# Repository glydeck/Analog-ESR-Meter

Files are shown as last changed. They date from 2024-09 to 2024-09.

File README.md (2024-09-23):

-----------------------------------------------
# Analog ESR Meter
## Created with KiCAD, OpenSCAD, & Inkscape
#### Posted by glydeck 9/12/2024
-----------------------------------------------

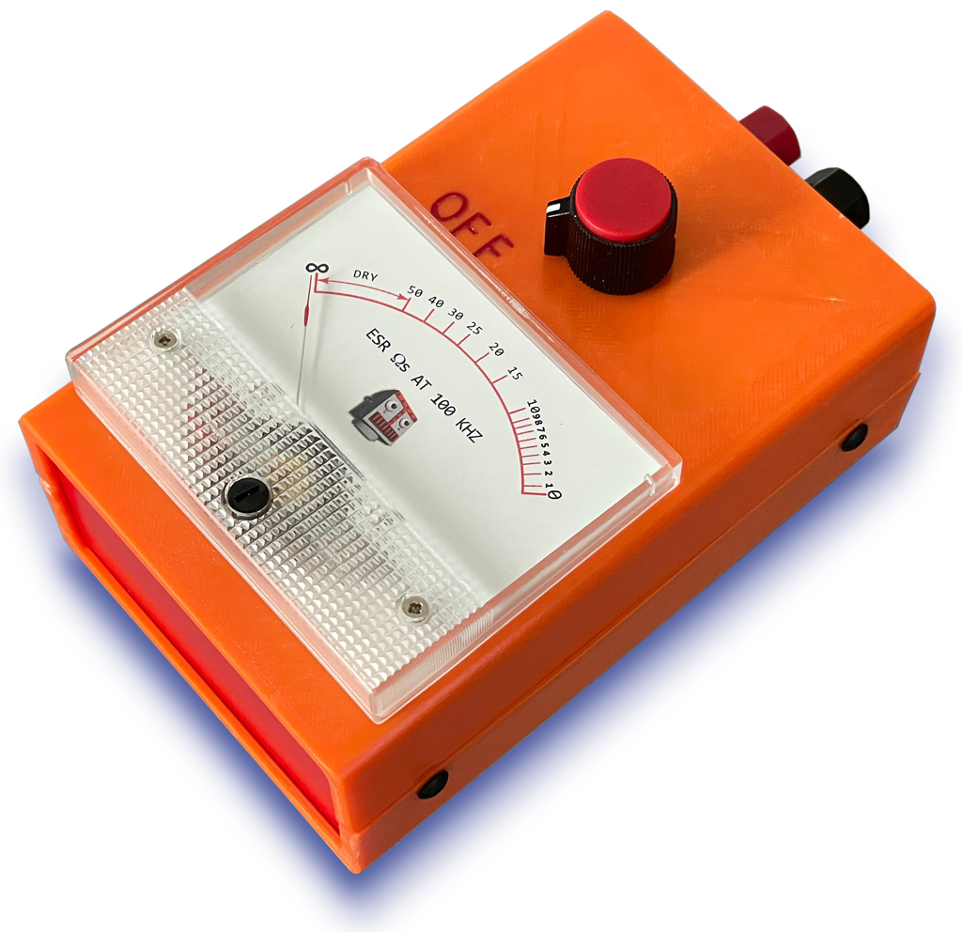
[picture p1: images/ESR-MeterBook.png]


## Introduction
This ESR Meter is an updated version of two articles written by me for Elektor Magazine.

- [**Elektor**](https://www.elektormagazine.com/)
- [**A Simple Analog ESR Meter**](https://www.elektormagazine.com/labs/a-simple-analog-esr-meter)
- [**My First PCB**](https://www.elektormagazine.com/magazine/elektor-261/60678)

The ESR Meter is basically an AC Ohmmeter with special scales and protective circuitry. It provides a continuous reading of series resistance in electrolytic capacitors. It operates at 100 kHz to keep the capacitive reactance factor near zero. The remaining series resistance is due to the electrolyte between the capacitor plates and indicates the state of dryness. Capacitor termination problems also show up plainly due to the continuous ohmic reading.

Additional information including parts list, schematic and circuit description can be found in the file **ESR Meter Manual.pdf** which is included in this repository.

## Requirements to Make your Own ESR Meter
Versions of the following programs:
- [**KiCad EDA**](https://www.kicad.org/)
- [**OpenSCAD**](https://openscad.org/)
- [**Inkscape**](https://github.com/inkscape/inkscape)
- [**The files in this repository**](https://github.com/glydeck/Analog-ESR-Meter)
## Contents

```
    README.md                -This document
    ESR Meter Manual.pdf     -Details for using the meter
    ESR_Box-OpenSCAD         -OpenSCAD code for the meter case
    ESR_Box-STL              -3D printable files for the case
    ESR_Meter_KicadProject   -KiCad project for circuit board
    ESR_MeterScale           -SVG file for the meter scale
    ESR_resources            -Various PDF files
    images                   -Images used throughout the project
```
### KiCad Project

##### 3D KiCad Rendering
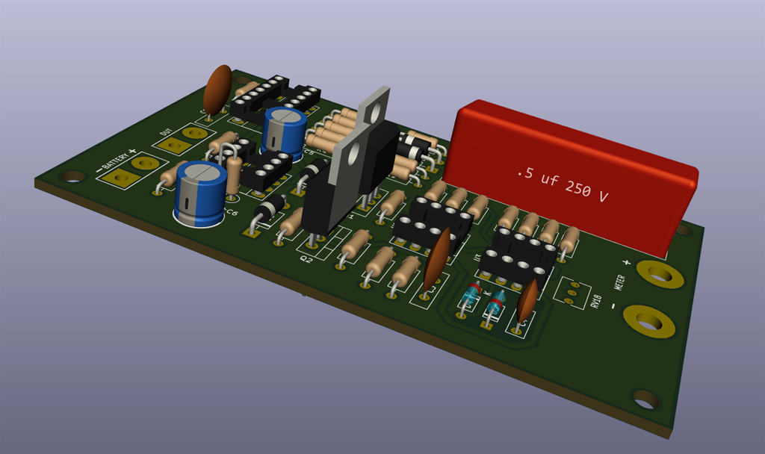
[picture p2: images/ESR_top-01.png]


This project uses a depreciated version of KiCad (Version 5.0.2-5 Mac OSX). At some point in the future I hope to update this to a newer version. For now the files for making the PCB are open source on OSH Park.  Boards can be ordered directly from them as well.
- [**OSH Park ESR Meter Boards**](https://oshpark.com/shared_projects/dSvuQNhP)

##### PCB Top View
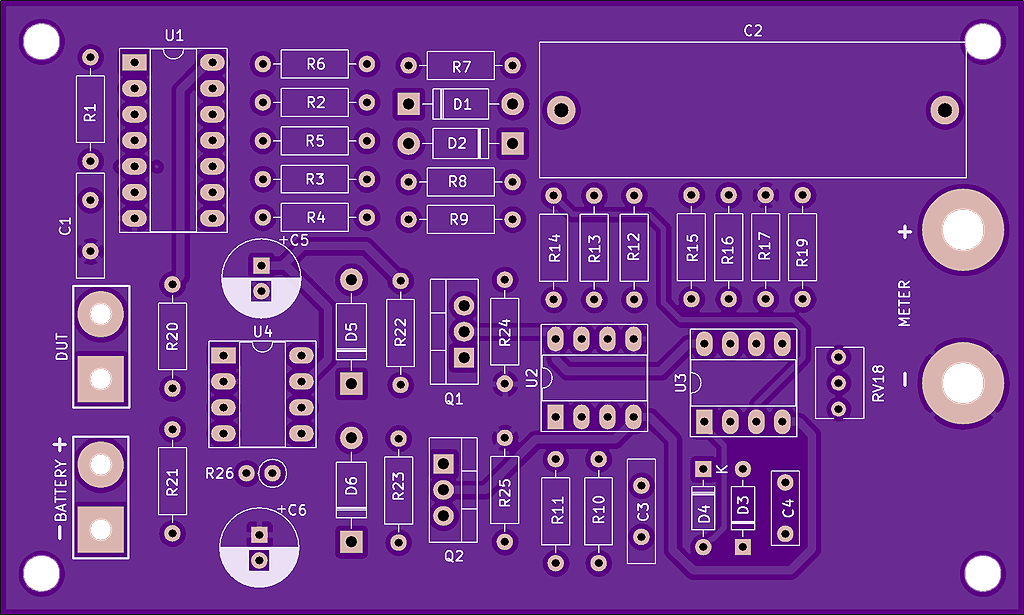
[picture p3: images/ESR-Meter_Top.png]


##### PCB Bottom View
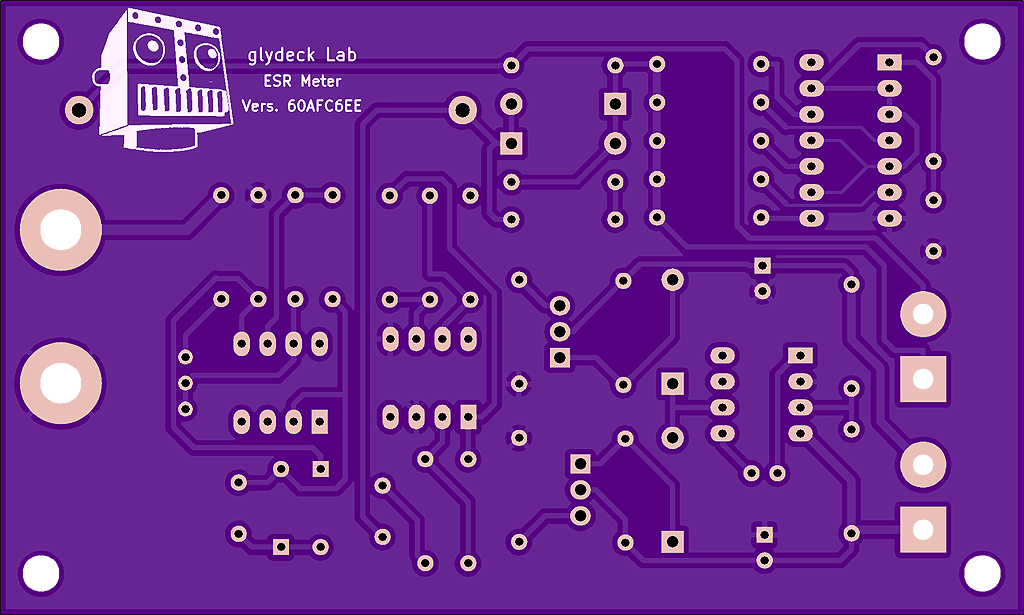
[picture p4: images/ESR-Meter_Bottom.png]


## Meter Case

##### Meter Case Rendered in Blender
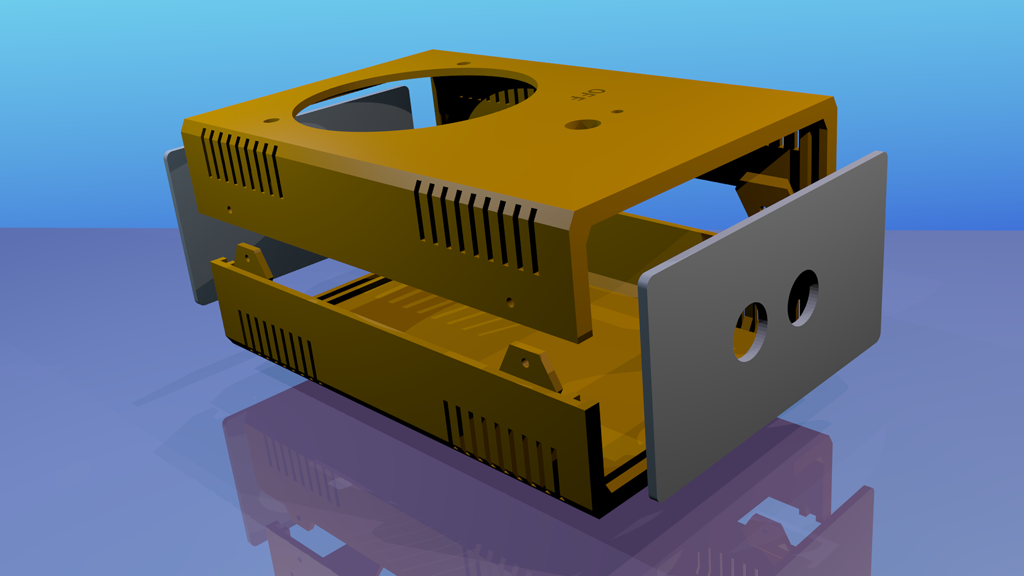
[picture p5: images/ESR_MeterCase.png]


I found the OpenSCAD code for the case on Thingverse:
- [**Thingverse-Ultimate Box Maker**](https://www.thingiverse.com/thing:2938921)

The original code and conncept can be traced back to the French Blog **Hearty GFX**: 
- [**Hearty GFX**](http://heartygfx.blogspot.com/2016/01/the-ultimate-box-maker.html)
 
The code has been maintained and improved on by Joel Ebel on GitHub:
- [**GitHub-Ultimate Box Maker**](https://github.com/jbebel/Ultimate-Box-Maker)

The **Box Maker** code does not accomidate adding holes to the top or bottom of the case.  It also does not accomidate custom geometries, such as the battery holder, being added to the inside of the box.

In the OpenScad file **ESR_Box_all.scad** the extra holes in the top of the case and battery holder are included at the end of the file. These added geometries including holes for the meter, potentiometer, added battery cage are included starting on line 419.  The Battery holder runs from line 432 to line 487. The holes for the meter, switch and text are difference geometries subtracted from the case. This code runs from line 496 thru line 569.

##### Meter Case Rendered in OpenSCAD
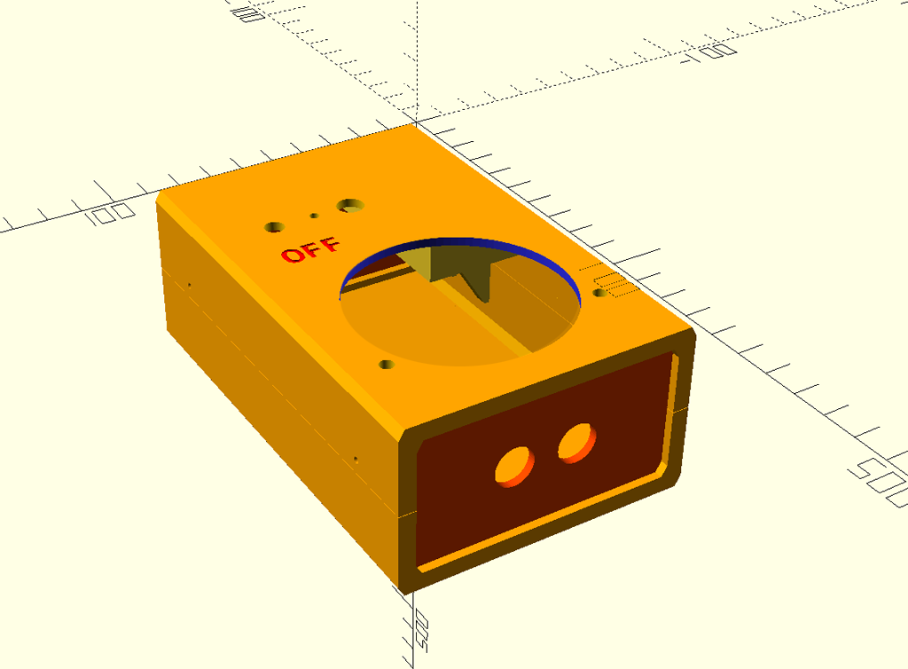
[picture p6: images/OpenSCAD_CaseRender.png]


### STL Files

There are two sets of STL files that are 3D printer ready.  I used Cura to generate the the G-Code for my printer and printed the case with a Creality Ender Model 3 printer.

The version one folder has a seperate bracket to help hold the 9 volt battery in place.  This piece would need to be glued in place on the bottom shell wall.

The version two folder this bracket is integral to the print of the bottom shell of the case.

## Meter Scale
The Meter scale graphic was created using **Inkscape**.  
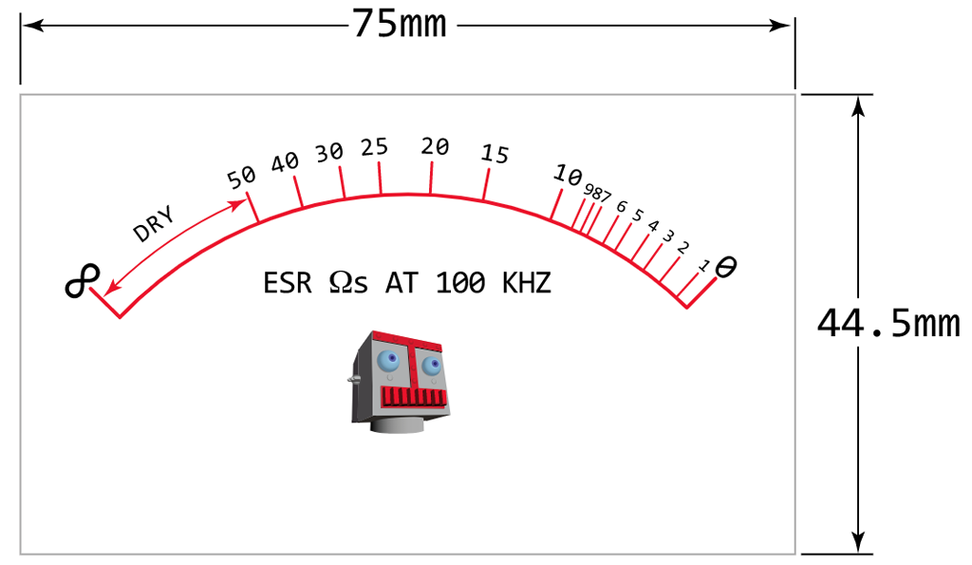
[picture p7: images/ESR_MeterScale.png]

## Assembly of ESR Meter
The meter is very easy to assemble.  After stuffing the Printed Circuit Board with components wires can be attached to to the PCB.  These wires can then be attached to the components in the case.  That includes potentiometer with integrated on/off switch, the binding posts and the 9V battery clip.  Two images are provided to show those connections.  When completed the PCB can be turned over and bolted to the back of the meter.  The meter acts as a holding device for the circuit board.

#### Stuffed Board
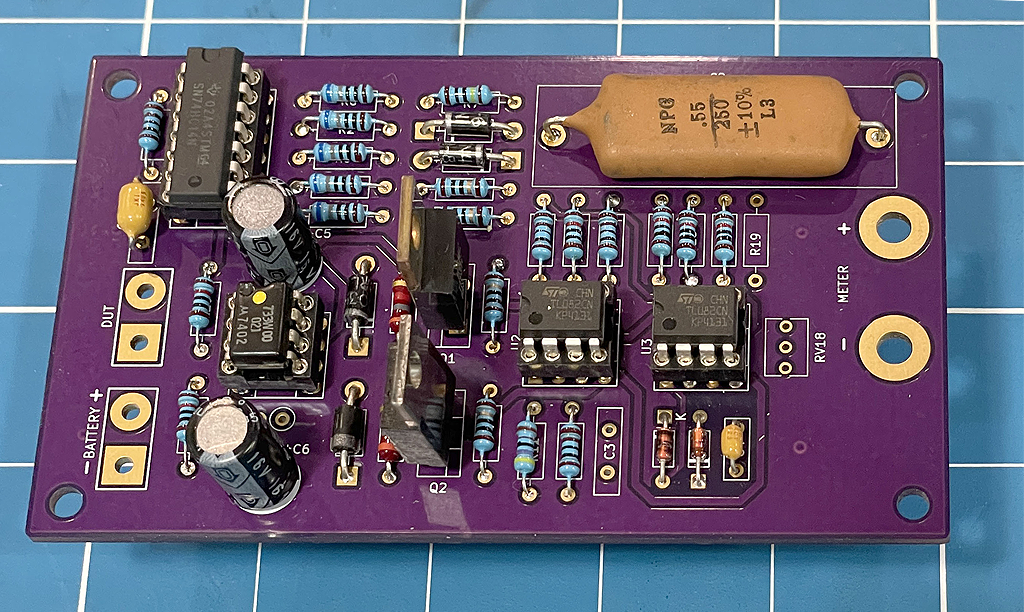
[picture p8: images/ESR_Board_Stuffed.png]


#### Wiring to Potentiometer, Binding Posts, & Battery Clip
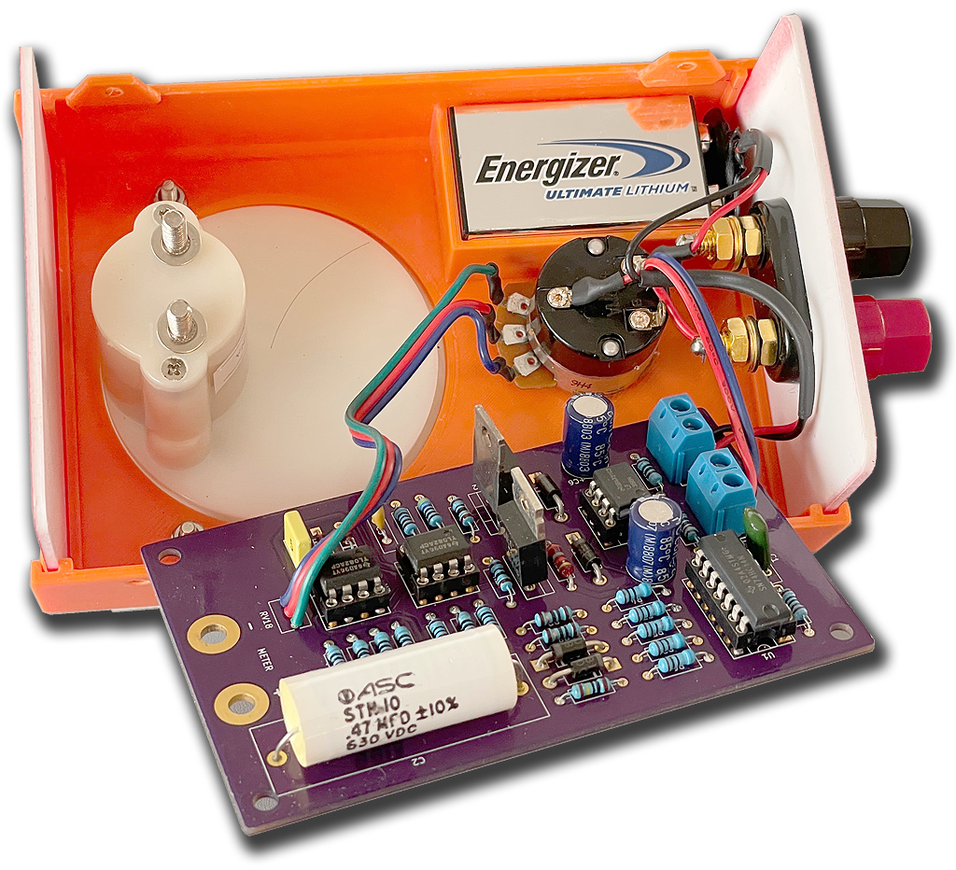
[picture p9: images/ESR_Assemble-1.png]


#### Closer View of Internal Wiring
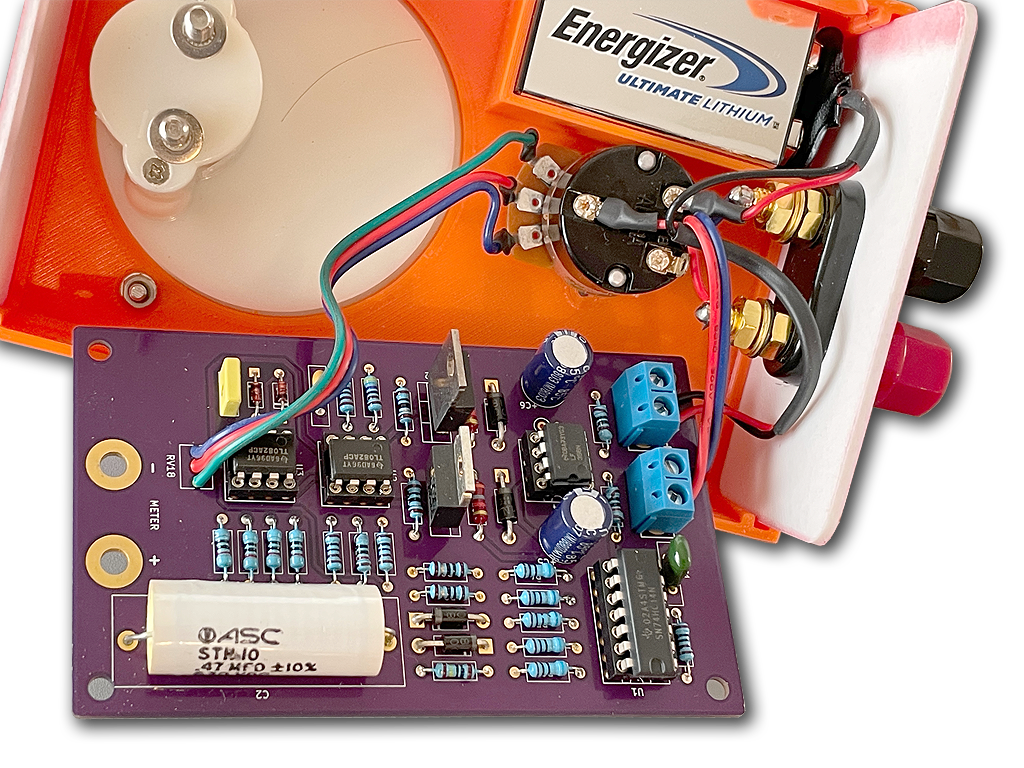
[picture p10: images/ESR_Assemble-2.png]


#### Board Attached to the Meter
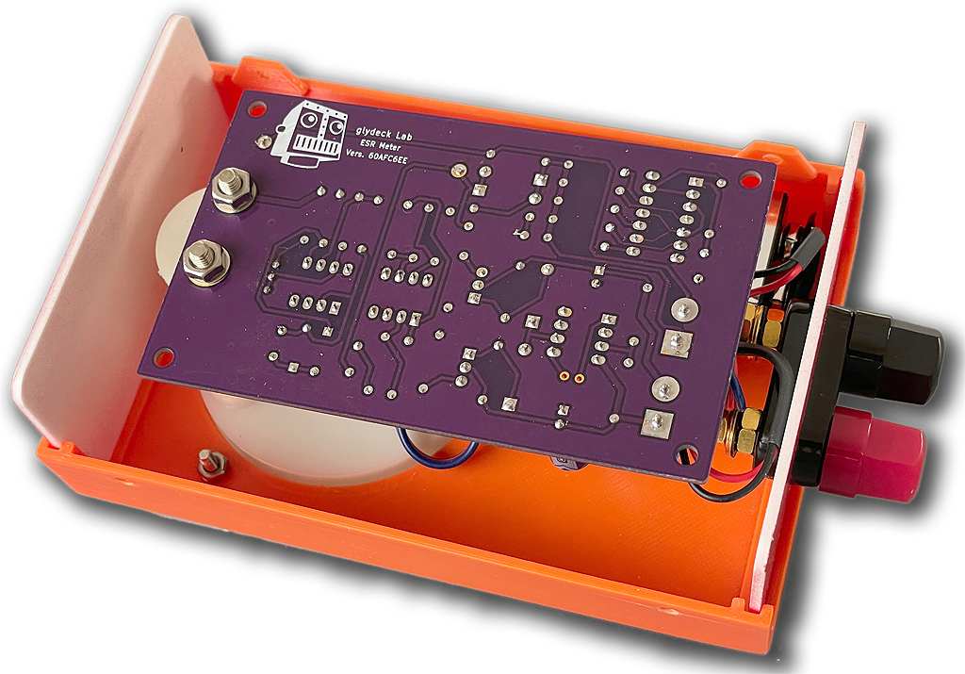
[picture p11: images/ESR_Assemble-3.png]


### ESR Resources
Description of included PDF files relevant to this project:

- Insert Analog_Panel_Meter.pdf - **Meter Cutout**
- sboa068.pdf - **Burr Brown App Note Absolute Value Circuits**
- Schmitt_Trigger_Oscillators.pdf - **Schmitt Trigger Oscillators**
- snoa998.pdf - **Texas Instruments App Note Relaxation oscillator circuit**
- US4216424.pdf - **Untited States Patent for an ESR Meter**
- US6677764.pdf - **United States Patent for Protecting Test Equipment**

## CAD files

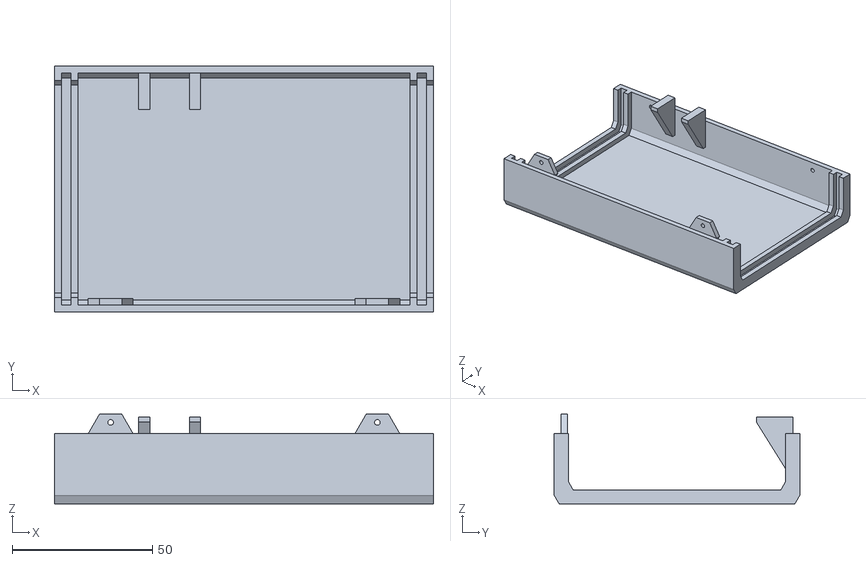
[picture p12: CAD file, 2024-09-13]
ESR_Box-STL/Version_02/ESR_Box_bottom_w-rotate.stl
135.0 x 87.5 x 31.9

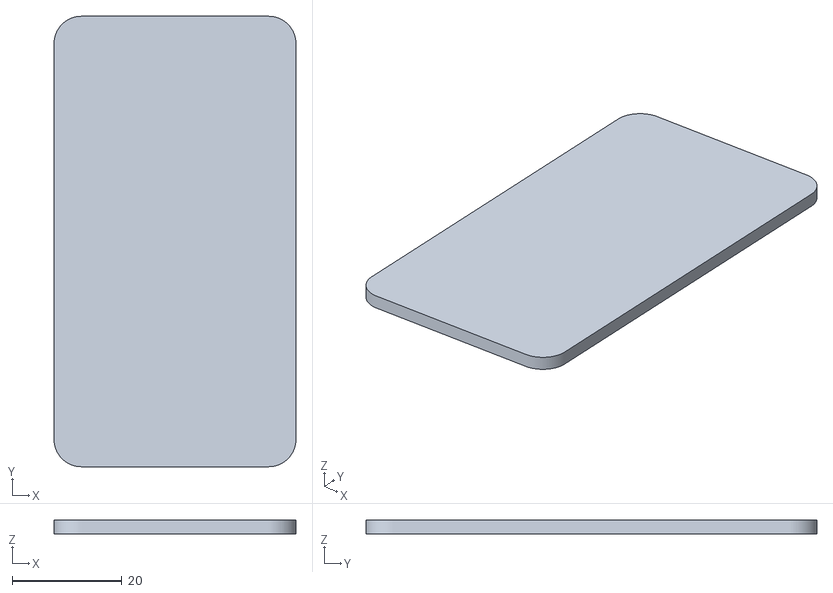
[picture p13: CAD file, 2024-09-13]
ESR_Box-STL/Version_02/ESR_Box_back.stl
44.1 x 82.1 x 2.50

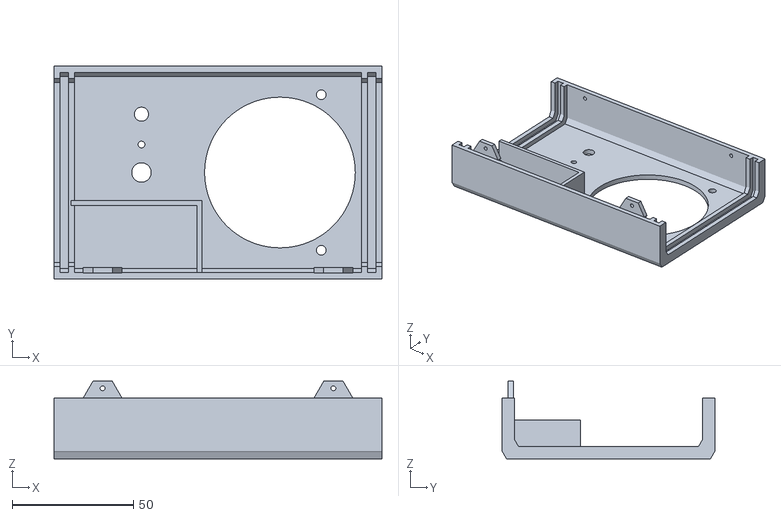
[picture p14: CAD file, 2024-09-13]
ESR_Box-STL/Version_02/ESR_Box_top_w-rotate.stl
135.0 x 87.5 x 31.9

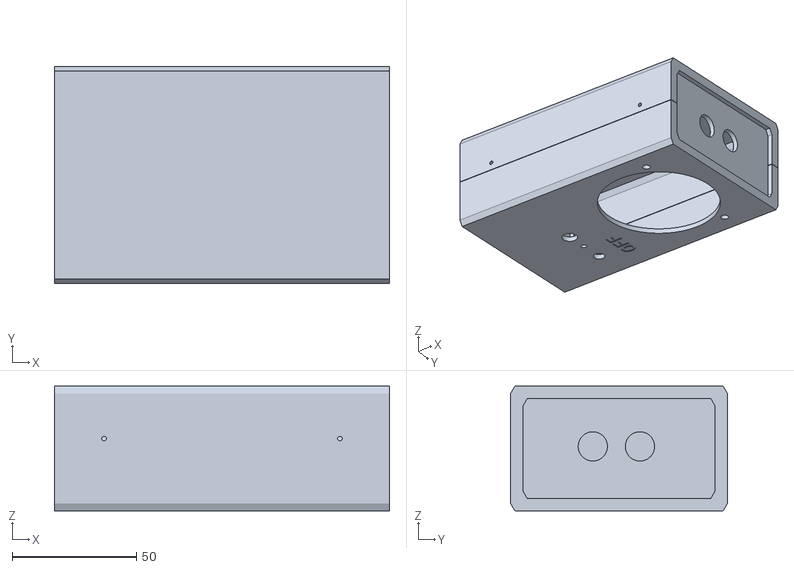
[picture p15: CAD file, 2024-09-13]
ESR_Box-STL/Version_02/ESR_Box_all.stl
135.0 x 87.5 x 50.2

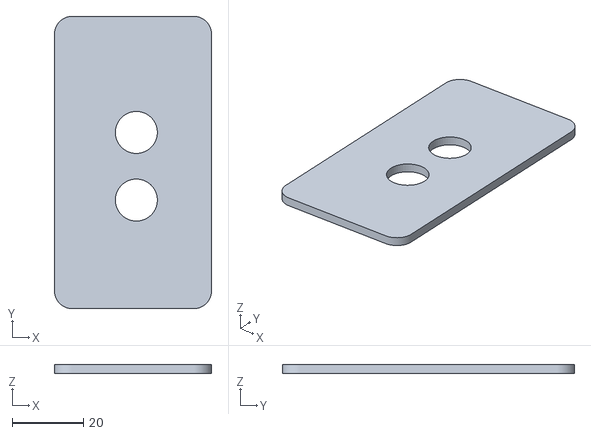
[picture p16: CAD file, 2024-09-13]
ESR_Box-STL/Version_02/ESR_Box_front.stl
44.1 x 82.1 x 2.50

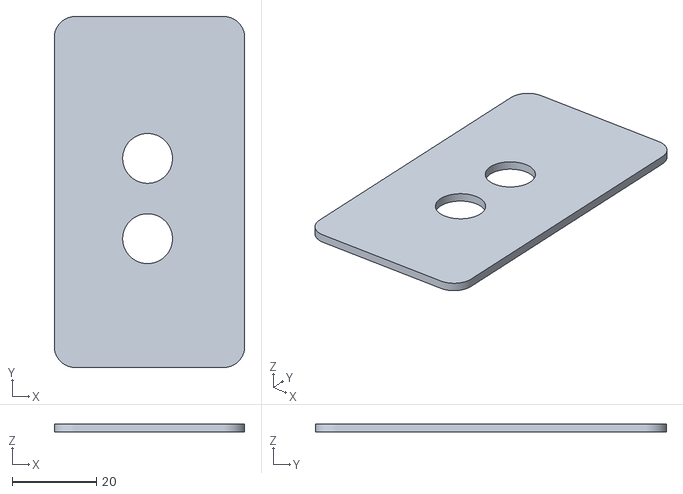
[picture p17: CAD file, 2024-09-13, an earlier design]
ESR_Box-STL/Version_01/ESR_Box_front_f5.stl
45.1 x 83.1 x 2.00

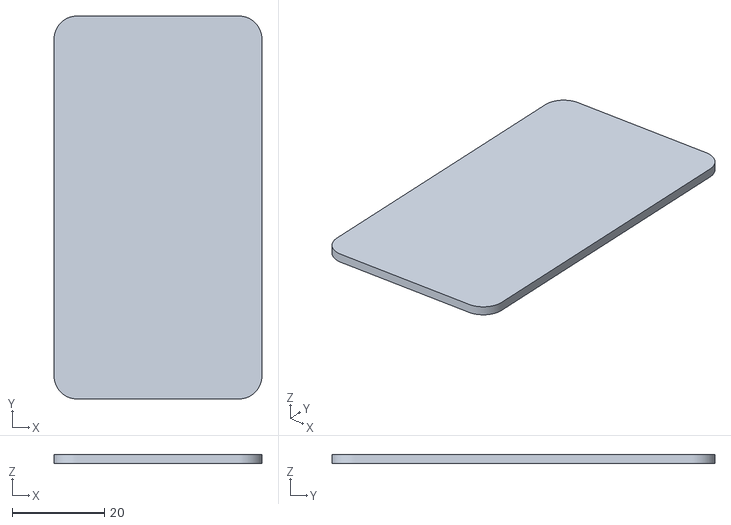
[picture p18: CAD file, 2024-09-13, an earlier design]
ESR_Box-STL/Version_01/ESR_Box_back_f5.stl
45.1 x 83.1 x 2.00

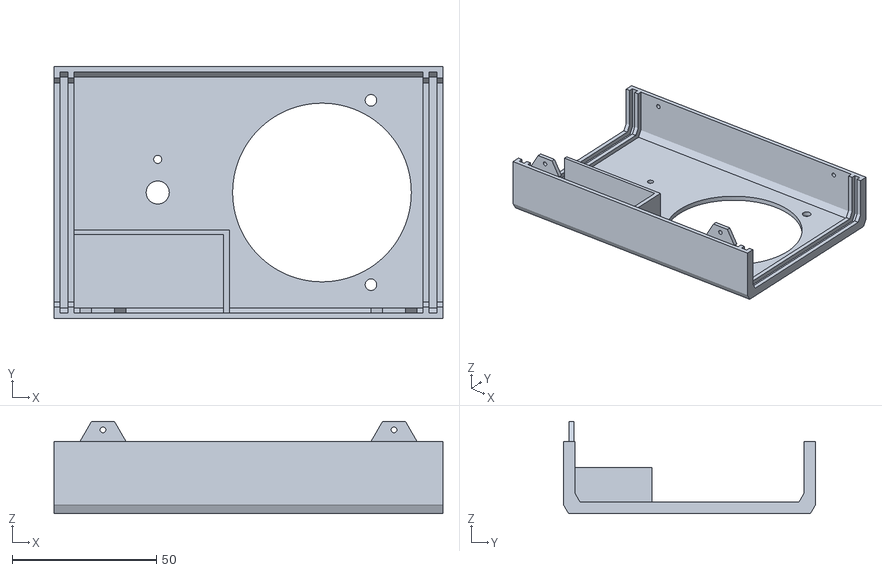
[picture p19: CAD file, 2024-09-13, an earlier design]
ESR_Box-STL/Version_01/ESR_Box_top.stl
135.0 x 87.5 x 31.9

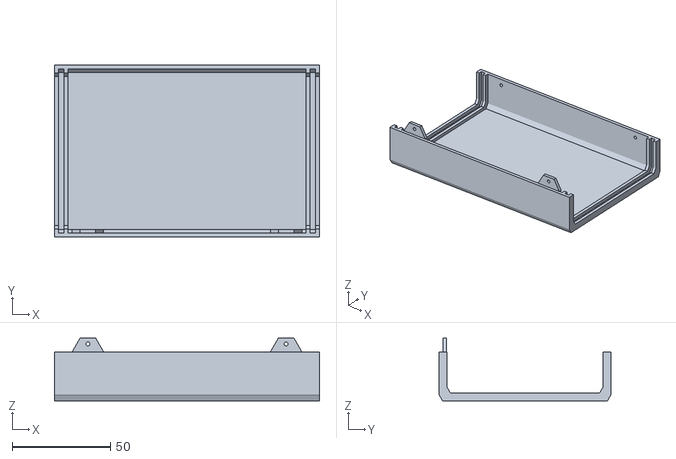
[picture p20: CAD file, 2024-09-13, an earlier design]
ESR_Box-STL/Version_01/ESR_Box_bottom.stl
135.0 x 87.5 x 31.9

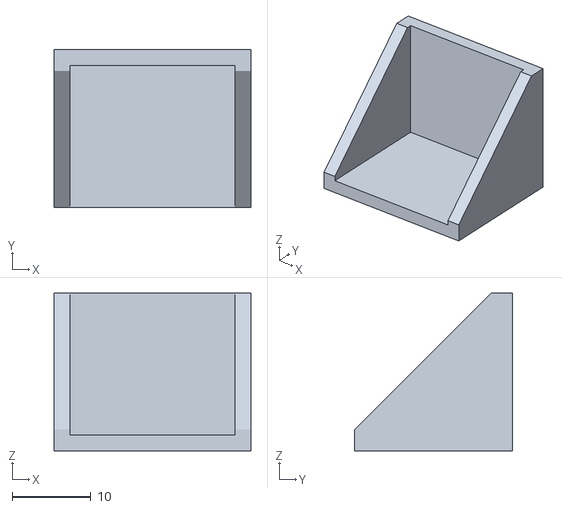
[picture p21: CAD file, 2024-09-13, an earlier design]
ESR_Box-STL/Version_01/battery_Bracket.stl
25.0 x 20.0 x 20.0

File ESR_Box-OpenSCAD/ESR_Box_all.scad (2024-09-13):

$vpr = [237, 0, 301];
$vpt = [62, 44, 29];
$vpd = 471;


/*//////////////////////////////////////////////////////////////////
              -   FB Aka Heartman/Hearty 2016
              -   OpenScad Parametric Box
              -   http://heartygfx.blogspot.com
              -   https://www.thingiverse.com/thing:2938921
              -   https://github.com/jbebel/Ultimate-Box-Maker             
              -   CC BY-NC 3.0 License 
////////////////////////////////////////////////////////////////////

12/02/2016 - Fixed minor bug 
28/02/2016 - Added holes ventilation option                    
09/03/2016 - Added PCB feet support, fixed the shell artefact on export mode. 

*/ ////////////////////////// - Info - //////////////////////////////

// All coordinates are starting as integrated circuit pins.
// From the top view :

//   CoordD           <---       CoordC
//                                 ^
//                                 ^
//                                 ^
//   CoordA           --->       CoordB

////////////////////////////////////////////////////////////////////

/////////////////////////// - Box parameters - //////////////////////

/* [Box dimensions] */
// - Longueur - Length  
Length = 135;
// - Largeur - Width
Width = 88;
// - Hauteur - Height  
Height = 50;
// - Epaisseur - Wall thickness  
Thick = 2.5; //[2:5]  

/* [Box options] */
// - DiamÃ¨tre Coin arrondi - Filet diameter  
Filet = 2; //[0.1:12] 
// - lissage de l'arrondi - Filet smoothness  
Resolution = 1; //[1:100] 
// - TolÃ©rance - Tolerance (Panel/rails gap)
m = 0.9;
// Pieds PCB - PCB feet (x4) 
PCBFeet = 0; // [0:No, 1:Yes]
// - Decorations to ventilation holes
Vent = 0; // [0:No, 1:Yes]
// - Decoration-Holes width (in mm)
Vent_width = 0;

/////////////////////////// - PCB parameters - //////////////////////

/* [PCB_Feet] */
//All dimensions are from the center foot axis

// - Coin bas gauche - Low left corner X position
PCBPosX = 0;
// - Coin bas gauche - Low left corner Y position
PCBPosY = 0;
// - Longueur PCB - PCB Length
PCBLength = 0;
// - Largeur PCB - PCB Width
PCBWidth = 0;
// - Heuteur pied - Feet height
FootHeight = 0;
// - DiamÃ¨tre pied - Foot diameter
FootDia = 0;
// - DiamÃ¨tre trou - Hole diameter
FootHole = 0;

////////////////////////////////////////////////////////////////////////
//////////////////////// <- Render Manager -> //////////////////////////
////////////////////////////////////////////////////////////////////////

/* [STL element to export] */
//Coque haut - Top shell
TShell = 1; // [0:No, 1:Yes]
//Coque bas- Bottom shell
BShell = 1; // [0:No, 1:Yes]
//Panneau avant - Front panel
FPanL = 1; // [0:No, 1:Yes]
//Panneau arriÃ¨re - Back panel  
BPanL = 1; // [0:No, 1:Yes]

/* [Hidden] */
// - Couleur coque - Shell color  
Couleur1 = "Orange";
// - Couleur panneaux - Panels color    
Couleur2 = "OrangeRed";
// Thick X 2 - making decorations thicker if it is a vent to make sure they go through shell
Dec_Thick = Vent ? Thick * 2 : Thick;
// - Depth decoration
Dec_size = Vent ? Thick * 2 : 0.8;

////////////////// - Generic rounded box - ///////////////

module RoundBox($a = Length, $b = Width, $c = Height) { // Cube bords arrondis
  $fn = Resolution;
  translate([0, Filet, Filet]) {
    minkowski() {
      cube([$a - (Length / 2), $b - (2 * Filet), $c - (2 * Filet)], center = false);
      rotate([0, 90, 0]) {
        cylinder(r = Filet, h = Length / 2, center = false);
      }
    }
  }
} // End of RoundBox Module

////////////////////////////////// - Module Coque/Shell - //////////////////////////////////         

module Coque() { //Coque - Shell  
  Thick = Thick * 2;
  difference() {
    difference() { //sides decoration
      union() {
        difference() { //soustraction de la forme centrale - Substraction Fileted box

          difference() { //soustraction cube median - Median cube slicer
            union() { //union               
              difference() { //Coque    
                RoundBox();
                translate([Thick / 2, Thick / 2, Thick / 2]) {
                  RoundBox($a = Length - Thick, $b = Width - Thick, $c = Height - Thick);
                }
              } //Fin diff Coque                            
              difference() { //largeur Rails        
                translate([Thick + m, Thick / 2, Thick / 2]) { // Rails
                  RoundBox($a = Length - ((2 * Thick) + (2 * m)), $b = Width - Thick, $c = Height - (Thick * 2));
                } //fin Rails
                translate([((Thick + m / 2) * 1.55), Thick / 2, Thick / 2 + 0.1]) { // +0.1 added to avoid the artefact
                  RoundBox($a = Length - ((Thick * 3) + 2 * m), $b = Width - Thick, $c = Height - Thick);
                }
              } //Fin largeur Rails
            } //Fin union                                   
            translate([-Thick, -Thick, Height / 2]) { // Cube Ã  soustraire
              cube([Length + 100, Width + 100, Height], center = false);
            }
          } //fin soustraction cube median - End Median cube slicer
          translate([-Thick / 2, Thick, Thick]) { // Forme de soustraction centrale 
            RoundBox($a = Length + Thick, $b = Width - Thick * 2, $c = Height - Thick);
          }
        }

        difference() { // wall fixation box legs
          union() {
            translate([3 * Thick + 5, Thick, Height / 2]) {
              rotate([90, 0, 0]) {
                $fn = 6;
                cylinder(d = 16, Thick / 2);
              }
            }

            translate([Length - ((3 * Thick) + 5), Thick, Height / 2]) {
              rotate([90, 0, 0]) {
                $fn = 6;
                cylinder(d = 16, Thick / 2);
              }
            }

          }
          translate([4, Thick + Filet, Height / 2 - 57]) {
            rotate([45, 0, 0]) {
              cube([Length, 40, 40]);
            }
          }
          translate([0, -(Thick * 1.46), Height / 2]) {
            cube([Length, Thick * 2, 10]);
          }
        } //Fin fixation box legs
      }

      union() { // outbox sides decorations

        for (i = [0: Thick: Length / 4]) {

          // Ventilation holes part code submitted by Ettie - Thanks ;) 
          translate([10 + i, -Dec_Thick + Dec_size, 1]) {
            cube([Vent_width, Dec_Thick, Height / 4]);
          }
          translate([(Length - 10) - i, -Dec_Thick + Dec_size, 1]) {
            cube([Vent_width, Dec_Thick, Height / 4]);
          }
          translate([(Length - 10) - i, Width - Dec_size, 1]) {
            cube([Vent_width, Dec_Thick, Height / 4]);
          }
          translate([10 + i, Width - Dec_size, 1]) {
            cube([Vent_width, Dec_Thick, Height / 4]);
          }

        } // fin de for
        // }
      } //fin union decoration
    } //fin difference decoration

    union() { //sides holes
      $fn = 50;
      translate([3 * Thick + 5, 20, Height / 2 + 4]) {
        rotate([90, 0, 0]) {
          cylinder(d = 2, 20);
        }
      }
      translate([Length - ((3 * Thick) + 5), 20, Height / 2 + 4]) {
        rotate([90, 0, 0]) {
          cylinder(d = 2, 20);
        }
      }
      translate([3 * Thick + 5, Width + 5, Height / 2 - 4]) {
        rotate([90, 0, 0]) {
          cylinder(d = 2, 20);
        }
      }
      translate([Length - ((3 * Thick) + 5), Width + 5, Height / 2 - 4]) {
        rotate([90, 0, 0]) {
          cylinder(d = 2, 20);
        }
      }
    } //fin de sides holes

  } //fin de difference holes
} // fin coque 

////////////////////////////// - Experiment - ///////////////////////////////////////////

/////////////////////// - Foot with base filet - /////////////////////////////
module foot(FootDia, FootHole, FootHeight) {
  Filet = 2;
  color(Couleur1)
  translate([0, 0, Filet - 1.5])
  difference() {

    difference() {
      //translate ([0,0,-Thick]){
      cylinder(d = FootDia + Filet, FootHeight - Thick, $fn = 100);
      //}
      rotate_extrude($fn = 100) {
        translate([(FootDia + Filet * 2) / 2, Filet, 0]) {
          minkowski() {
            square(10);
            circle(Filet, $fn = 100);
          }
        }
      }
    }
    cylinder(d = FootHole, FootHeight + 1, $fn = 100);
  }
} // Fin module foot

module Feet() {
  //////////////////// - PCB only visible in the preview mode - /////////////////////    
  translate([3 * Thick + 2, Thick + 5, FootHeight + (Thick / 2) - 0.5]) {

    %
    square([PCBLength + 10, PCBWidth + 10]);
    translate([PCBLength / 2, PCBWidth / 2, 0.5]) {
      color("Olive") %
        text("PCB", halign = "center", valign = "center", font = "Arial black");
    }
  } // Fin PCB
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

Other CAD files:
ESR_Box-OpenSCAD/ESR_Box_back.scad
ESR_Box-OpenSCAD/ESR_Box_bottom.scad
ESR_Box-OpenSCAD/ESR_Box_bottom_w-rotate.scad
ESR_Box-OpenSCAD/ESR_Box_front.scad
ESR_Box-OpenSCAD/ESR_Box_top.scad
ESR_Box-OpenSCAD/ESR_Box_top_w-rotate.scad

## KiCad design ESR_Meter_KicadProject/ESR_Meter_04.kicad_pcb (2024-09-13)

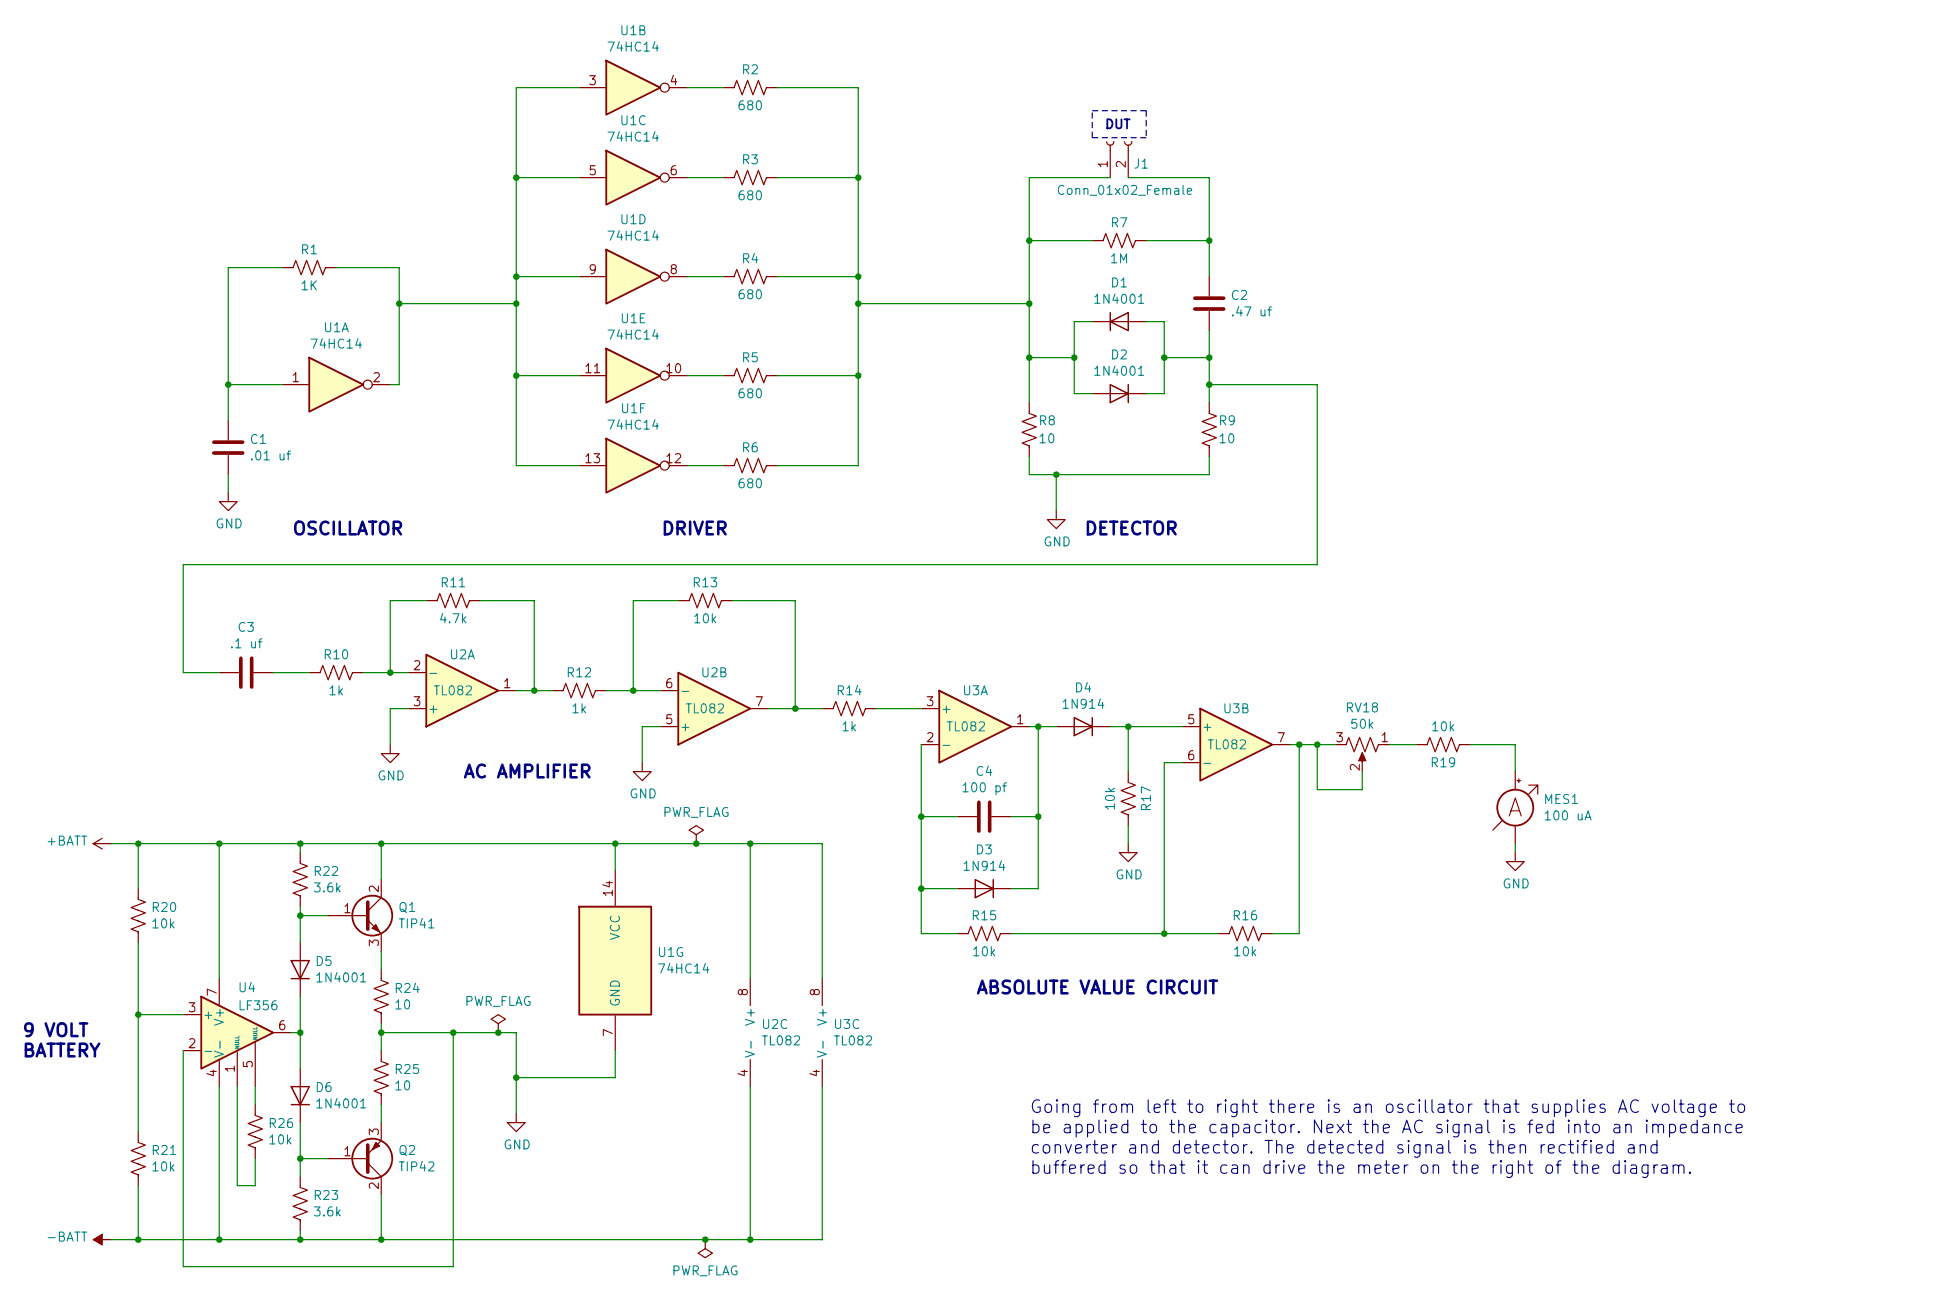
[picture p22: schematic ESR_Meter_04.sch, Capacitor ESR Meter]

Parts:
C1: .01 uf; C_Disc_D10.0mm_W2.5mm_P5.00mm
C2: .47 uf; C_Rect_L41.5mm_W13.0mm_P37.50mm_MKS4
C3: .1 uf; C_Disc_D10.0mm_W2.5mm_P5.00mm
C4: 100 pf; C_Disc_D7.0mm_W2.5mm_P5.00mm
D1, D2, D5, D6: 1N4001; D_DO-41_SOD81_P10.16mm_Horizontal
D3, D4: 1N914; D_DO-35_SOD27_P7.62mm_Horizontal
J1: Conn_01x02_Female; SolderWirePad_1x02_P7.62mm_Drill2mm
MES1: 100 uA; Analog Meter
Q1: TIP41; TO-220-3_Vertical
Q2: TIP42; TO-220-3_Vertical
R1: 1K; R_Axial_DIN0207_L6.3mm_D2.5mm_P10.16mm_Horizontal
R2, R3, R4, R5, R6: 680; R_Axial_DIN0207_L6.3mm_D2.5mm_P10.16mm_Horizontal
R7: 1M; R_Axial_DIN0207_L6.3mm_D2.5mm_P10.16mm_Horizontal
R8, R9, R24, R25: 10; R_Axial_DIN0207_L6.3mm_D2.5mm_P10.16mm_Horizontal
R10, R12, R14: 1k; R_Axial_DIN0207_L6.3mm_D2.5mm_P10.16mm_Horizontal
R11: 4.7k; R_Axial_DIN0207_L6.3mm_D2.5mm_P10.16mm_Horizontal
R13, R15, R16, R17, R19, R20, R21: 10k; R_Axial_DIN0207_L6.3mm_D2.5mm_P10.16mm_Horizontal
R22, R23: 3.6k; R_Axial_DIN0207_L6.3mm_D2.5mm_P10.16mm_Horizontal
R26: 10k; R_Axial_DIN0207_L6.3mm_D2.5mm_P2.54mm_Vertical
RV18: 50k; Potentiometer_Bourns_3266Y_Vertical
U1: 74HC14; DIP-14_W7.62mm_Socket_LongPads
U2, U3: TL082; DIP-8_W7.62mm_Socket_LongPads
U4: LF356; DIP-8_W7.62mm_Socket_LongPads

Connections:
+BATT: Q1.2 (C), R20.1, R22.1, U1.14 (VCC), U2.8 (V+), U3.8 (V+), U4.7 (V+); also elsewhere on the board
-BATT: Q2.2 (C), R21.2, R23.2, U2.4 (V-), U3.4 (V-), U4.4 (V-); also elsewhere on the board
GND: C1.1, MES1.1 (-), R8.1, R9.1, R17.1, R24.2, R25.1, U1.7 (GND), U2.3 (+), U2.5 (+), U4.2 (-); also elsewhere on the board
unnamed: C1.2, R1.2, U1.1
unnamed: C2.1, C3.2, D1.2 (A), D2.1 (K), R9.2
unnamed 5: C2.2, J1.2, R7.1; also elsewhere on the board
unnamed: C3.1, R10.2
unnamed: C4.1, D3.1 (K), D4.2 (A), U3.1
unnamed: C4.2, D3.2 (A), R15.2, U3.2 (-)
unnamed 9: D1.1 (K), D2.2 (A), J1.1, R2.1, R3.1, R4.1, R5.1, R6.1, R7.2, R8.2; also elsewhere on the board
unnamed: D4.1 (K), R17.2, U3.5 (+)
unnamed: D5.1 (K), D6.2 (A), U4.6
unnamed: D5.2 (A), Q1.1 (B), R22.2
unnamed: D6.1 (K), Q2.1 (B), R23.1
unnamed 14: MES1.2 (+), R19.2; also elsewhere on the board
unnamed: Q1.3 (E), R24.1
unnamed: Q2.3 (E), R25.2
unnamed: R1.1, U1.2, U1.3, U1.5, U1.9, U1.11, U1.13
unnamed: R2.2, U1.4
unnamed: R3.2, U1.6
unnamed: R4.2, U1.8
unnamed: R5.2, U1.10
unnamed: R6.2, U1.12
unnamed: R10.1, R11.2, U2.2 (-)
unnamed: R11.1, R12.2, U2.1
unnamed: R12.1, R13.2, U2.6 (-)
unnamed: R13.1, R14.2, U2.7
unnamed: R14.1, U3.3 (+)
unnamed: R15.1, R16.2, U3.6 (-)
unnamed: R16.1, RV18.2, RV18.3, U3.7
unnamed: R19.1, RV18.1
unnamed: R20.2, R21.1, U4.3 (+)
unnamed: R26.1, U4.5 (NULL)
unnamed: R26.2, U4.1 (NULL)

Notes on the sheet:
DUT
OSCILLATOR
DRIVER
DETECTOR
AC AMPLIFIER
ABSOLUTE VALUE CIRCUIT
Going from left to right there is an oscillator that supplies AC voltage to be applied to the capacitor. Next the AC signal is fed into an impedance converter and detector. The detected signal is then rectified and buffered so that it can drive the meter on the right of the diagram.
9 VOLT BATTERY

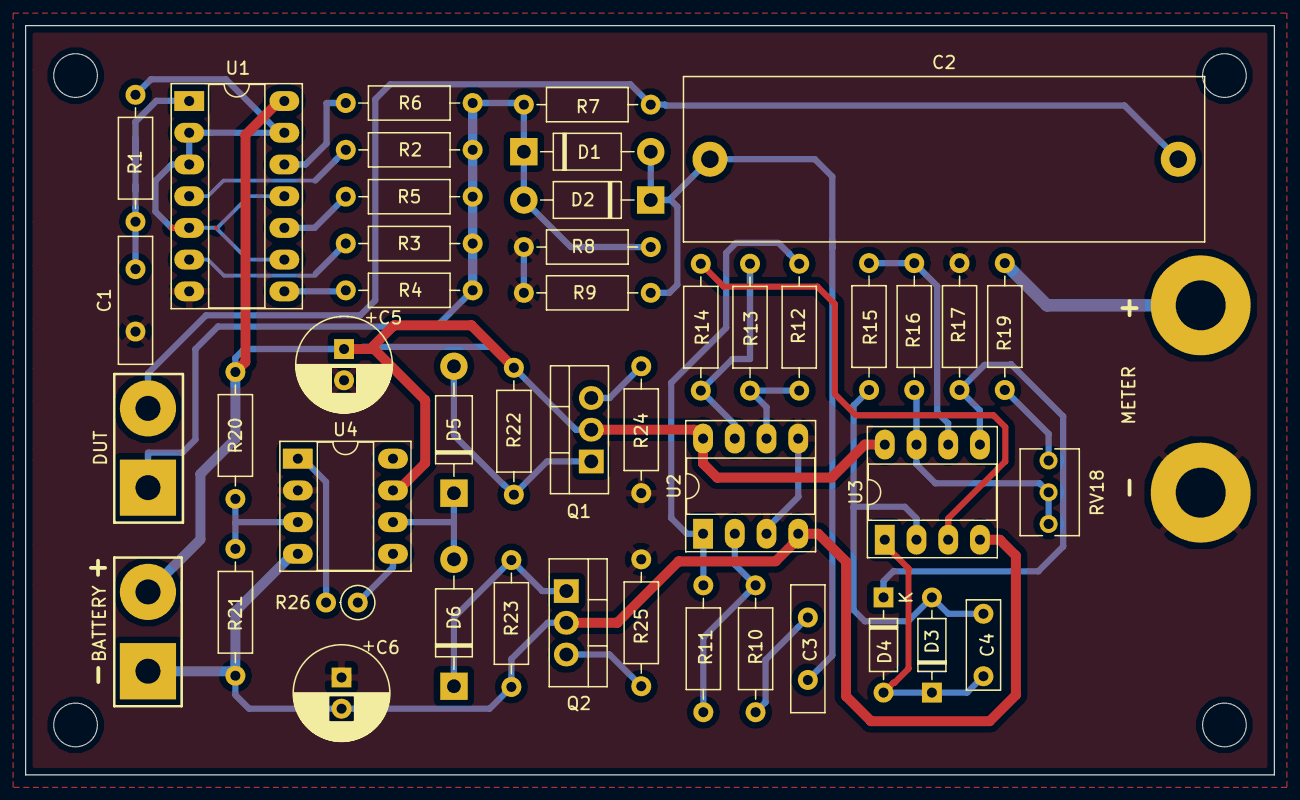
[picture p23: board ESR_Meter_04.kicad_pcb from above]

Board: 2 copper layers, 100.0 x 60.0 mm, 47 parts (0 on the bottom side), 34 nets.

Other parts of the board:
BATTERY: Conn_01x02_Female; SolderWirePad_1x02_P7.62mm_Drill2mm
C5, C6: CP_Radial_D7.5mm_P2.50mm
DUT: Conn_01x02_Female; SolderWirePad_1x02_P7.62mm_Drill2mm
METER: 500 uA; Analog Meter

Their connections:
+BATT: BATTERY.2, C5.1; also elsewhere on the board
-BATT: BATTERY.1, C6.2; also elsewhere on the board
GND: C5.2, C6.1, METER.1; also elsewhere on the board
unnamed 5: DUT.2; also elsewhere on the board
unnamed 9: DUT.1; also elsewhere on the board
unnamed 14: METER.2; also elsewhere on the board
